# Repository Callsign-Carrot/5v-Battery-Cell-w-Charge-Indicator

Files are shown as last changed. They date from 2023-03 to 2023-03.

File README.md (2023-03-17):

# 5v-Battery-Cell-w-Charge-Indicator
<h3>5v Battery cell inspired by Subnautica and Titanfall.</h3>

<p>This is a project that turns boring batteries into a satisfying mechanisim. Inspired by games like Subnautica and Titanfall, you simply insert and twist to plug it in. Designed to last a long time for circuits running 5v at < 1.5A. This circuit includes a <a href="https://www.ti.com/lit/ds/symlink/tps61023.pdf?HQS=dis-dk-null-digikeymode-dsf-pf-null-wwe&ts=1617863529482">TSP61023 boost converter</a>, <a href="https://www.mouser.com/datasheet/2/268/AVR32_16DD20_14_Prel_DataSheet_DS40002413-2997818.pdf">AVR16DD14 microcontroller</a>, and a <a href="https://www.analog.com/media/en/technical-documentation/data-sheets/MAX17048-MAX17049.pdf">MAX17048 Fuel gauge</a>. Device also features <a href="https://cdn-shop.adafruit.com/product-files/2686/SK6812MINI_REV.01-1-2.pdf">SK6812MINI RGB LEDs</a> for the outward facing indicator.</p>
<h5>Planned Features</h5>
<ul>
  <li>3D Model (already *mostly* done)</li>
  <li>Programming (Not even started :D)</li>
  <li>Animations for inidcator</li>
</ul>
<h3>ONLY USE PROTECTED LI-POs WITH THIS CIRCUIT :D</h3>
<div>
<h3>Circuit diagram</h3>
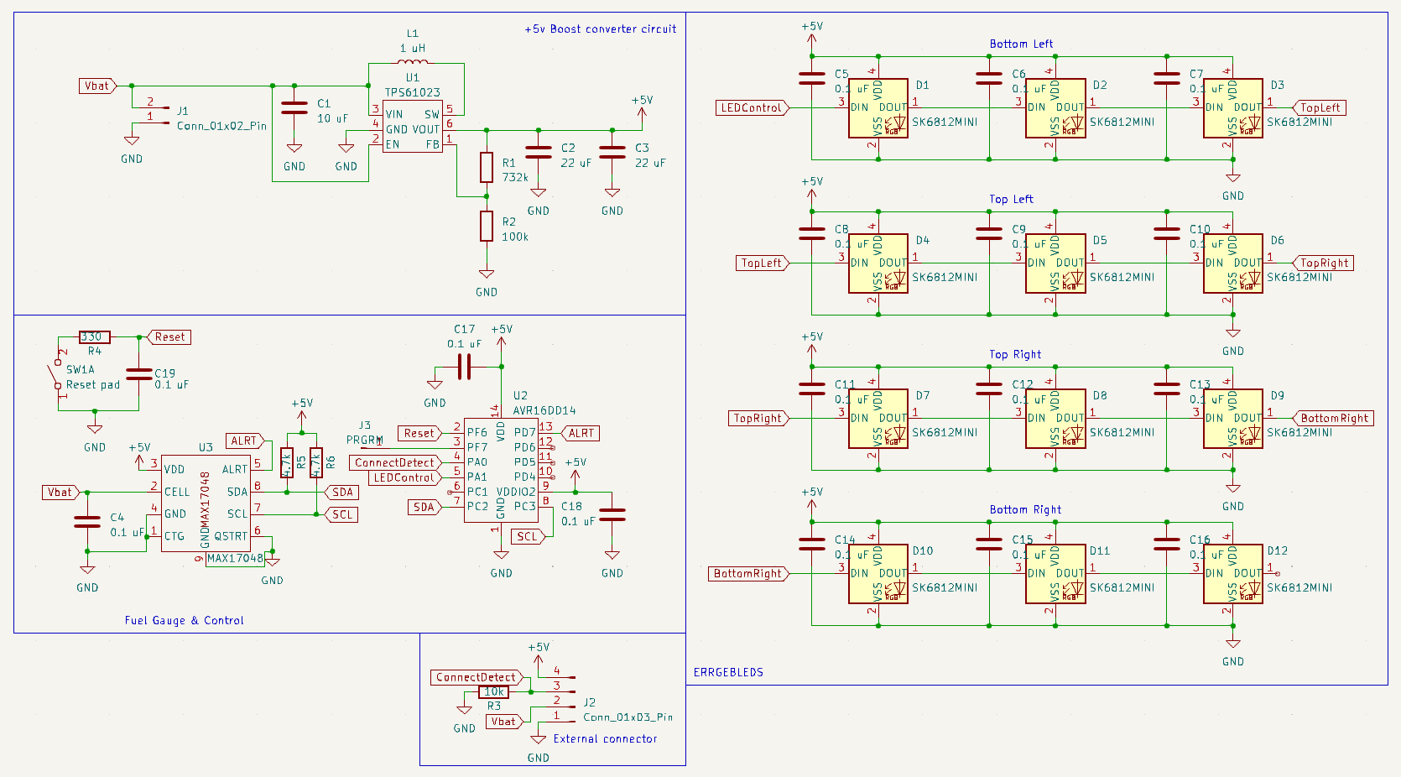
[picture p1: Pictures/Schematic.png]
Circuit schematic

<h3>Front of circuit board</h3>
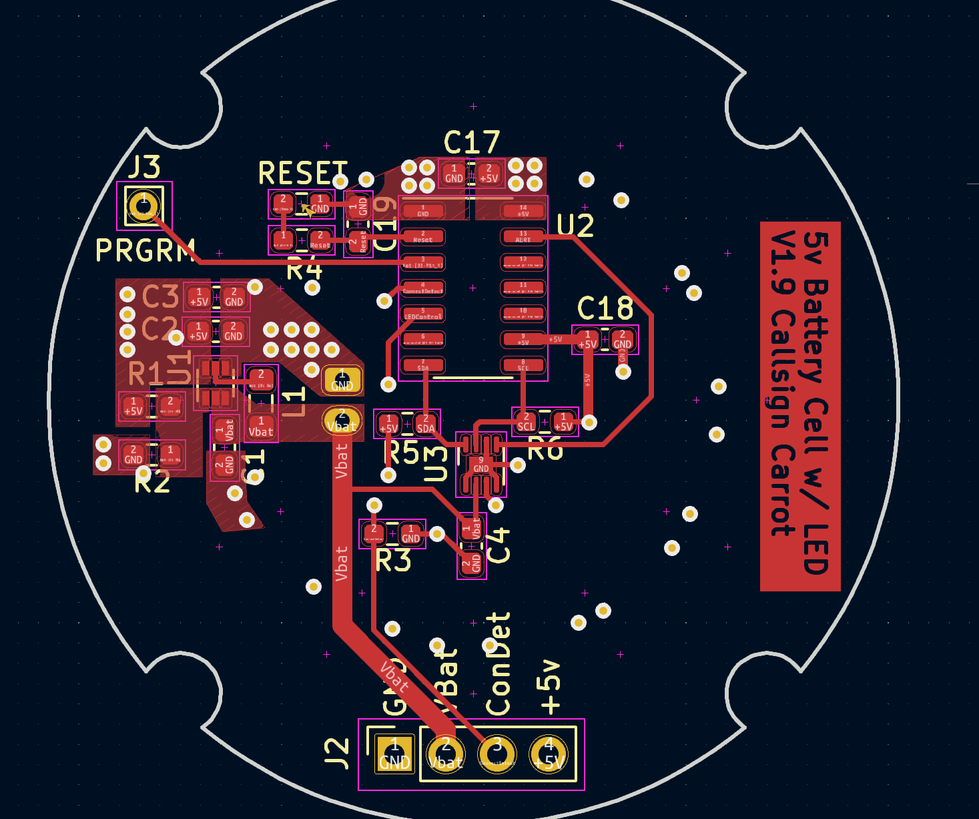
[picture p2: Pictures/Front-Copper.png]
Front of circuit board

<h3>Back of circuit board</h3>
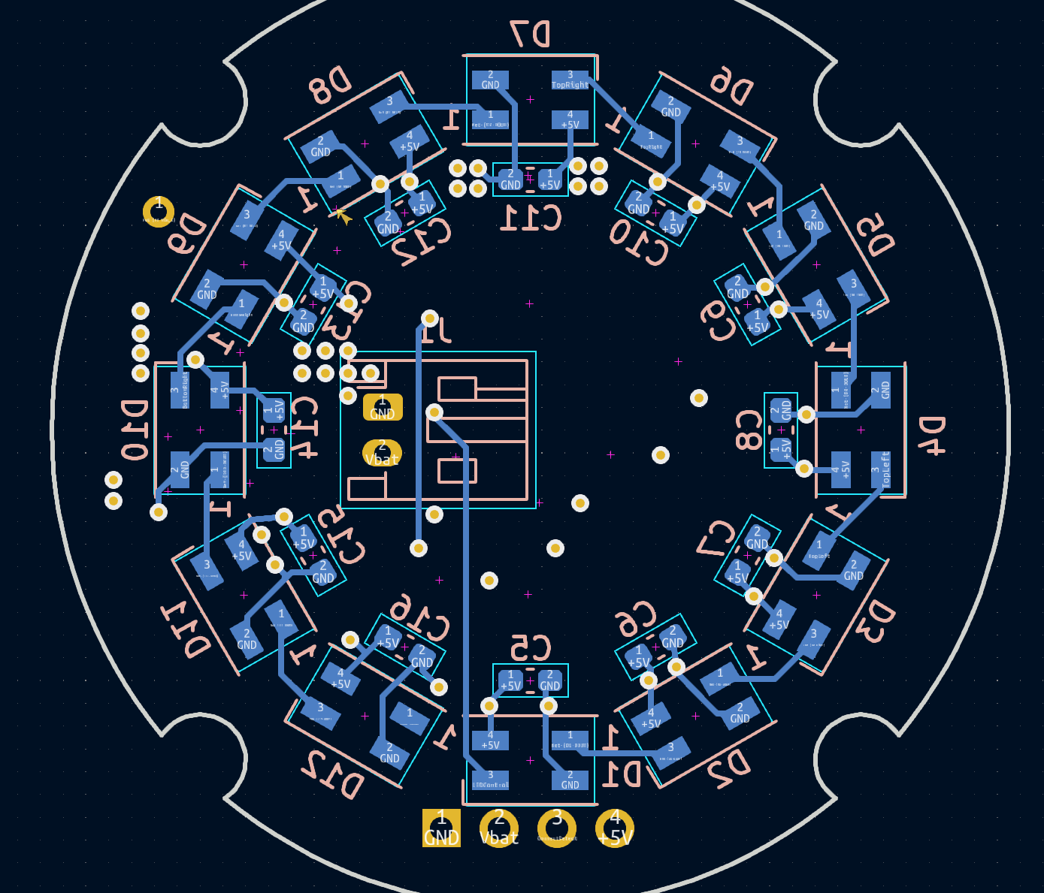
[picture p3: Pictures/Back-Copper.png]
Back of circuit board

</div>

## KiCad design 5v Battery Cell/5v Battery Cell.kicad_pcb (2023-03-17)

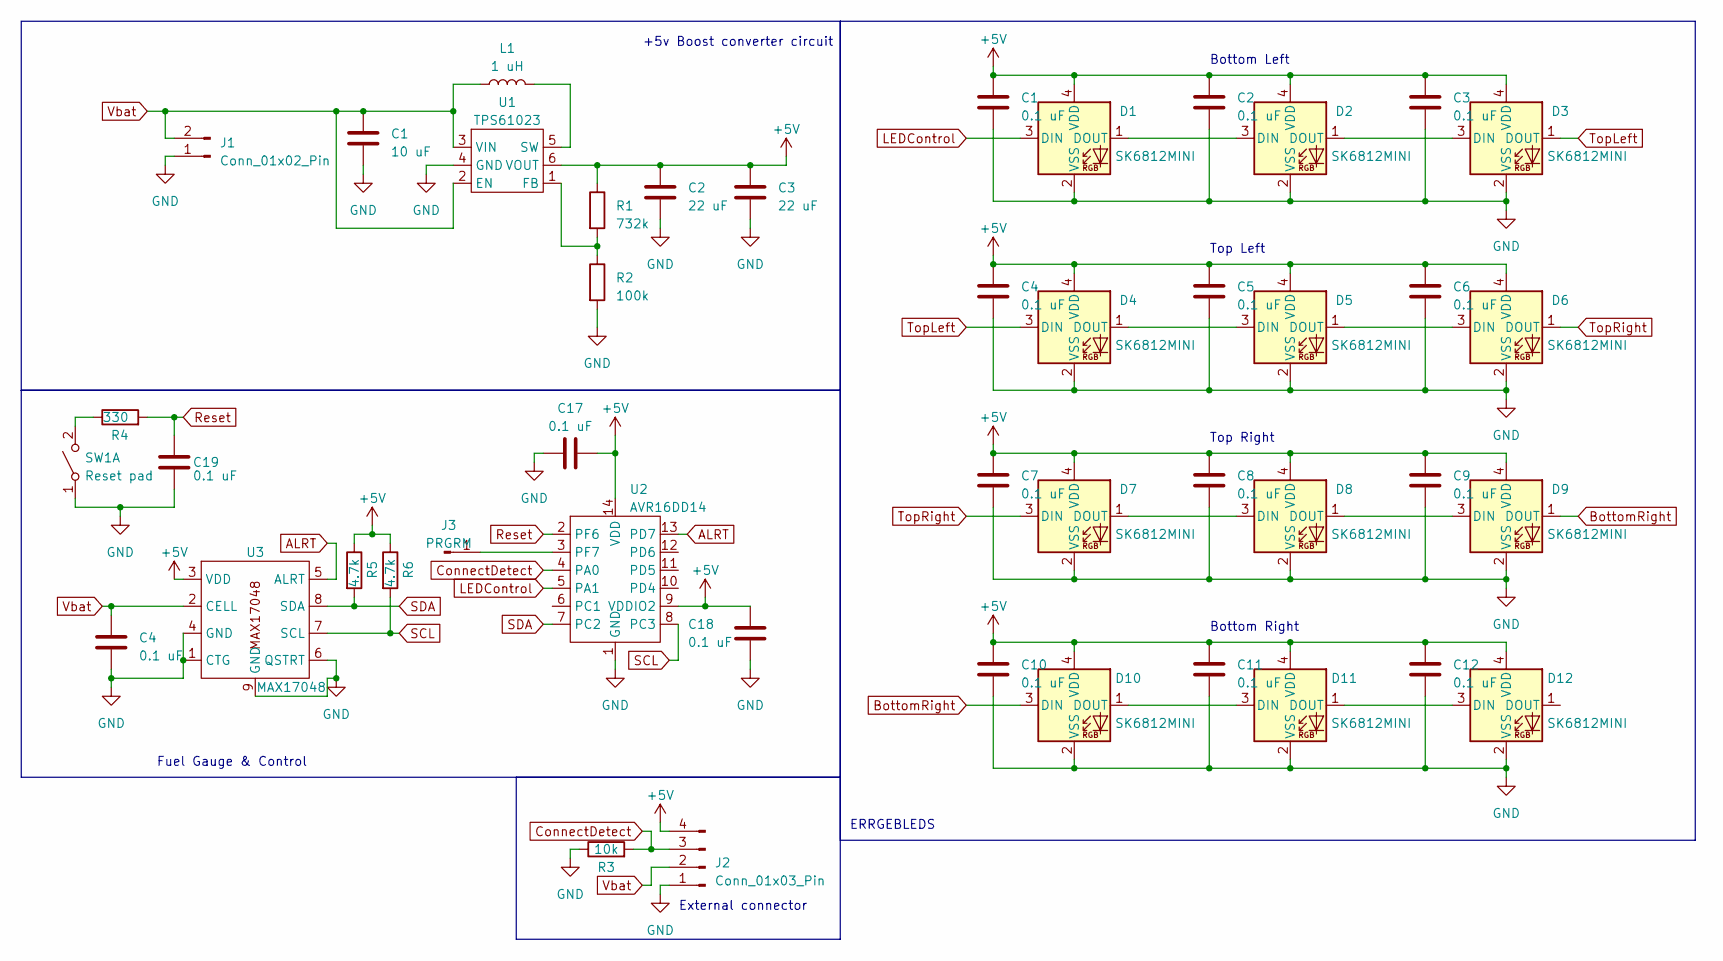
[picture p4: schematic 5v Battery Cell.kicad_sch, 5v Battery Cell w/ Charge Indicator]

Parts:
C1: 10 uF; C_0603_1608Metric_Pad1.08x0.95mm_HandSolder
C2: 22 uF; C_0603_1608Metric_Pad1.08x0.95mm_HandSolder
C3, C4, C5, C6, C7, C8, C9, C10, C11, C12, C17, C18, C19: 0.1 uF; C_0603_1608Metric_Pad1.08x0.95mm_HandSolder
D1, D2, D3, D4, D5, D6, D7, D8, D9, D10, D11, D12: SK6812MINI; LED_SK6812MINI_PLCC4_3.5x3.5mm_P1.75mm
J1: Conn_01x02_Pin; JST_PH_S2B-PH-K_1x02_P2.00mm_Horizontal
J2: Conn_01x03_Pin; PinSocket_1x04_P2.54mm_Vertical
J3: PRGRM; Pin_D0.7mm_L6.5mm_W1.8mm_FlatFork
L1: 1 uH; L_0805_2012Metric_Pad1.05x1.20mm_HandSolder
R1: 732k; R_0603_1608Metric_Pad0.98x0.95mm_HandSolder
R2: 100k; R_0603_1608Metric_Pad0.98x0.95mm_HandSolder
R3: 10k; R_0603_1608Metric_Pad0.98x0.95mm_HandSolder
R4: 330; R_0603_1608Metric_Pad0.98x0.95mm_HandSolder
R5, R6: 4.7k; R_0603_1608Metric_Pad0.98x0.95mm_HandSolder
SW1: Reset pad; R_0603_1608Metric_Pad0.98x0.95mm_HandSolder
U1: TPS61023; SOT-563
U2: AVR16DD14; SOIC-14_3.9x8.7mm_P1.27mm
U3: MAX17048; TDFN-8-1EP_2x2mm_P0.5mm_EP0.8x1.2mm

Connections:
ALRT: U2.13 (PD7), U3.5 (ALRT)
BottomRight: D9.1 (DOUT), D10.3 (DIN)
ConnectDetect: J2.3, R3.2, U2.4 (PA0)
GND: C1.2, C2.2, C3.2, C4.2, C5.2, C6.2, C7.2, C8.2, C9.2, C10.2, C11.2, C12.2, C17.1, C18.2, C19.1, D1.2 (VSS), D2.2 (VSS), D3.2 (VSS), D4.2 (VSS), D5.2 (VSS), D6.2 (VSS), D7.2 (VSS), D8.2 (VSS), D9.2 (VSS), D10.2 (VSS), D11.2 (VSS), D12.2 (VSS), J1.1, J2.1, R2.2, R3.1, SW1.1 (A), U1.4 (GND), U2.1 (GND), U3.1 (CTG), U3.4 (GND), U3.6 (QSTRT), U3.9 (GND); also elsewhere on the board
LEDControl: D1.3 (DIN), U2.5 (PA1)
unnamed: D1.1 (DOUT), D2.3 (DIN)
unnamed: D2.1 (DOUT), D3.3 (DIN)
unnamed: D4.1 (DOUT), D5.3 (DIN)
unnamed: D5.1 (DOUT), D6.3 (DIN)
unnamed: D7.1 (DOUT), D8.3 (DIN)
unnamed: D8.1 (DOUT), D9.3 (DIN)
unnamed: D10.1 (DOUT), D11.3 (DIN)
unnamed: D11.1 (DOUT), D12.3 (DIN)
unnamed: J3.1, U2.3 (PF7)
unnamed 14: R4.1, SW1.2 (B); also elsewhere on the board
unnamed: R1.2, R2.1, U1.1 (FB)
unnamed: L1.2, U1.5 (SW)
Reset: C19.2, R4.2, U2.2 (PF6)
SCL: R6.2, U2.8 (PC3), U3.7 (SCL)
SDA: R5.2, U2.7 (PC2), U3.8 (SDA)
TopLeft: D3.1 (DOUT), D4.3 (DIN)
TopRight: D6.1 (DOUT), D7.3 (DIN)

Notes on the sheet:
Bottom Left
Top Right
Fuel Gauge & Control
ERRGEBLEDS
Top Left
Bottom Right
+5v Boost converter circuit
External connector

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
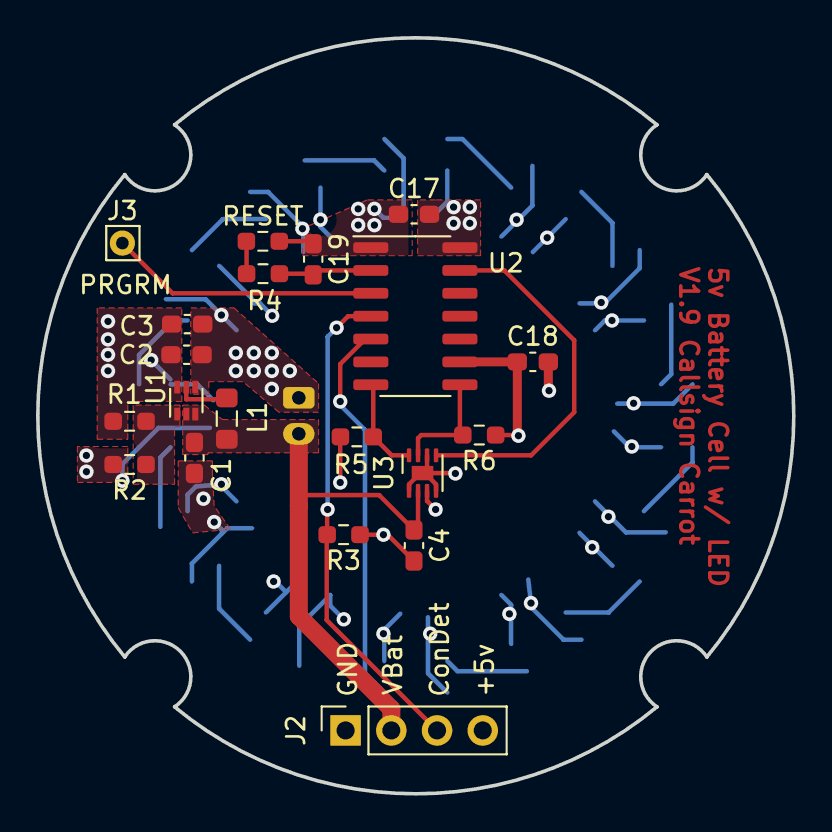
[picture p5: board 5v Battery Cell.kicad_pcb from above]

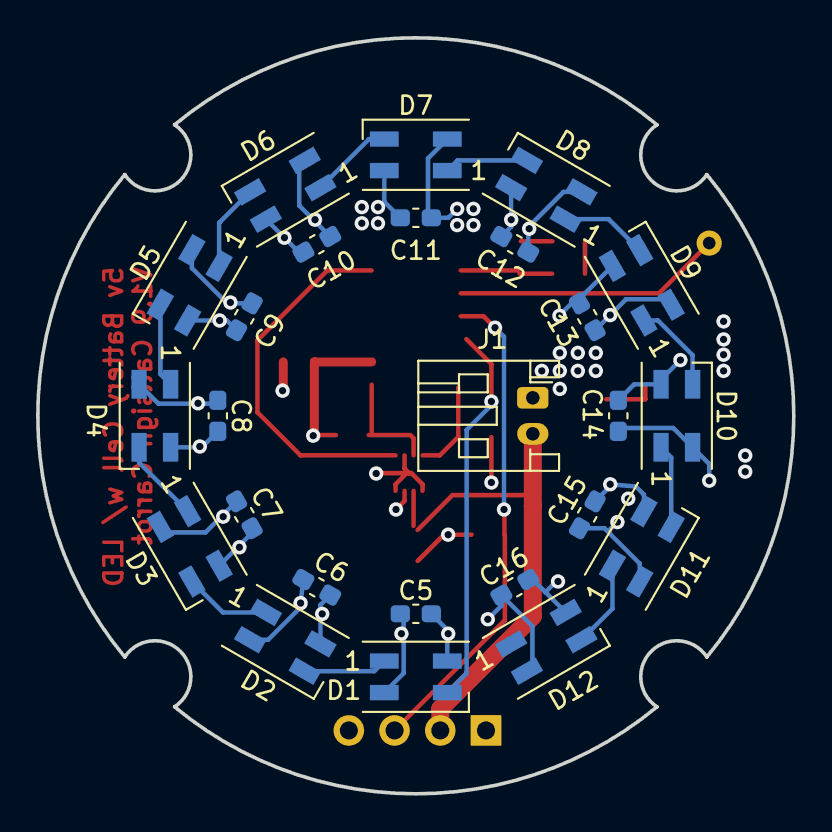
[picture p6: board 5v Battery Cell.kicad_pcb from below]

Board: 4 copper layers, 42.0 x 42.0 mm, 45 parts (25 on the bottom side), 24 nets.

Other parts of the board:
C13, C14, C15, C16: 0.1 uF; C_0603_1608Metric_Pad1.08x0.95mm_HandSolder
RESET: Reset pad; R_0603_1608Metric_Pad0.98x0.95mm_HandSolder

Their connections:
GND: C13.2, C14.2, C15.2, C16.2, RESET.1 (A); also elsewhere on the board
unnamed 14: RESET.2 (B); also elsewhere on the board

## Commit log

2023-03-14 Initial file upload.
    Uploaded first "finished" version of the project to share.
    [5v Battery Cell.kicad_pcb, 5v Battery Cell.kicad_sch]
2023-03-17 Major revisions to the circuit and PCB design.
    Swapped out the ATTiny204 for the AVR16DD14. Gives me extra room to work with. Updated PCB to actually be able to handle 1.5A draw from the battery, though it's never expected to reach that.
    [5v Battery Cell.kicad_pcb, 5v Battery Cell.kicad_sch]
2023-03-17 Updated issue dates.
    [5v Battery Cell.kicad_pcb, 5v Battery Cell.kicad_sch]
